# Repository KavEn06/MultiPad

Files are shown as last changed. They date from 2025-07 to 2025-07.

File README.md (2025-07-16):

# MultiPad


## Features
- Triple layer 3D printed case
- 128x32 OLED Display
- EC11 Rotary encoder for volume and scrolling through other shortcut layers 
- 6 keys
- Very cool swirly design – trust me, it looks awesome in person

## CAD Model
The CAD model is held together with 4 M3 screws and heatset inserts. It’s built in three layers: the bottom layer holds all the components, the middle layer keeps the switches in place, and the top layer is mainly there to look nice.

Case            |  Layers
:-------------------------:|:-------------------------:
 | 

The CAD model was made in OnShape. 

## PCB 
Here's the PCB! It utilizes a XIAO RP2040, which is connected to 6 switches, a 128x32 OLED display, and an EC11 rotary encoder. 

Schematic            |  PCB
:-------------------------:|:-------------------------:
 | 

Since I'm the goat, I got 0 errors after I did the DRC check. 😎

## BOM:
Here is a list of everything you would need to build the MultiPad

- 6x Cherry MX Switches
- 6x DSA Keycaps
- 4x M3x5x4 Heatset inserts
- 2X M3x12mm Bolts
- 1x 0.91" 128x32 OLED Display
- 1x EC11 Rotary Encoder
- 1x XIAO RP2040
- 1x Case (3 3D printed parts)

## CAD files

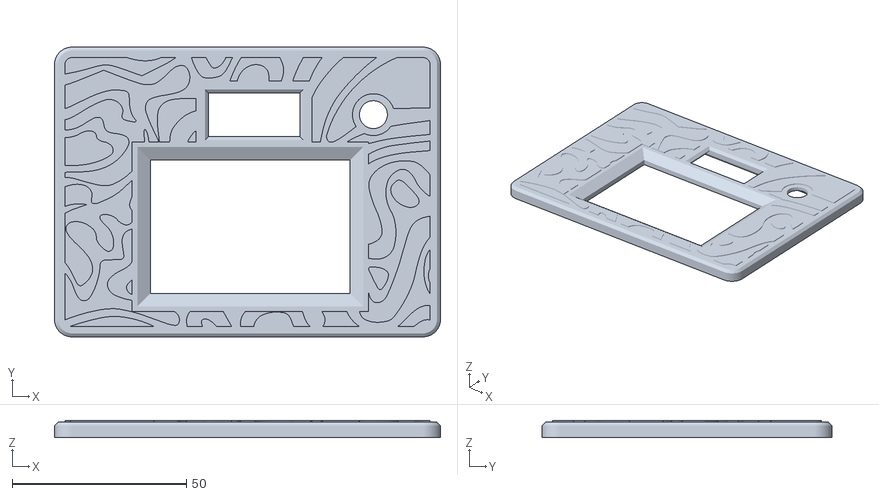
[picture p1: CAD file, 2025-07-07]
production/Top.stl
110.7 x 83.1 x 5.00

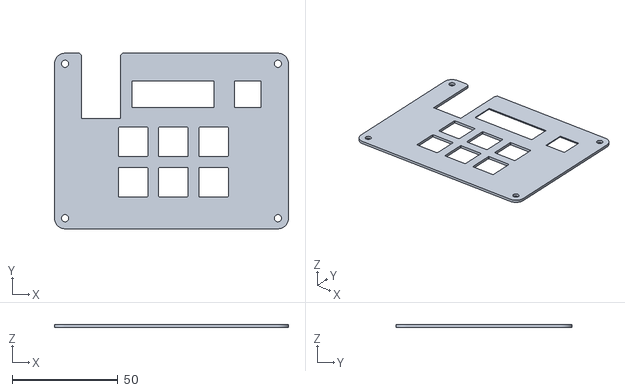
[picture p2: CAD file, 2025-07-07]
production/Middle.stl
110.8 x 83.1 x 1.40

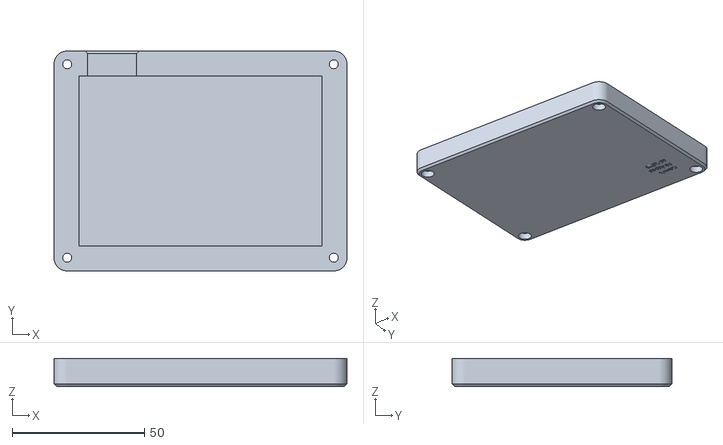
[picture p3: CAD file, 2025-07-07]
production/Bottom.stl
110.8 x 83.1 x 10.6

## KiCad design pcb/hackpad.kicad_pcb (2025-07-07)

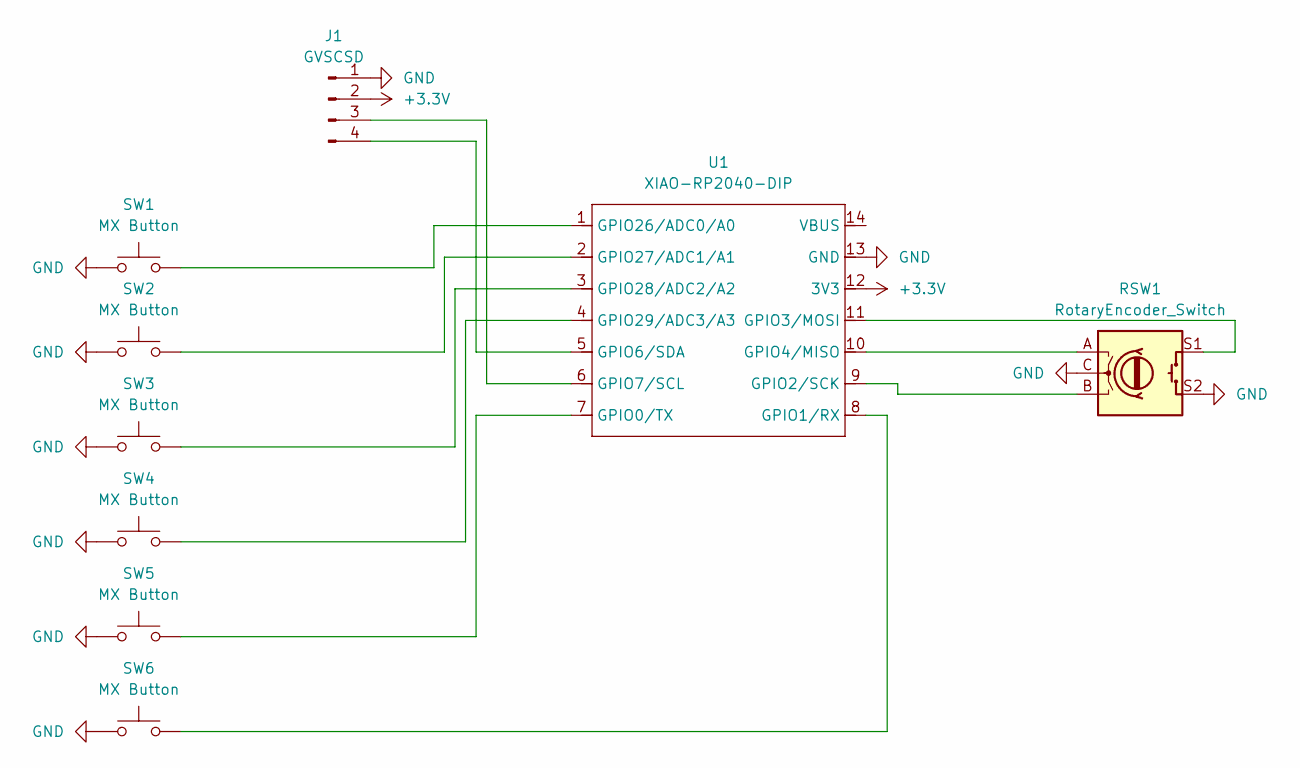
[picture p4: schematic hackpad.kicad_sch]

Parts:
J1: GVSCSD; SSD1306-0.91-OLED-4pin-128x32
RSW1: RotaryEncoder_Switch; RotaryEncoder_Alps_EC11E-Switch_Vertical_H20mm
SW1, SW2, SW3, SW4, SW5, SW6: MX Button; SW_Cherry_MX_1.00u_PCB
U1: XIAO-RP2040-DIP

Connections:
+3.3V: J1.2, U1.12 (3V3)
GND: J1.1, RSW1.C, RSW1.S2, SW1.1, SW2.1, SW3.1, SW4.1, SW5.1, SW6.1, U1.13 (GND)
unnamed: J1.3, U1.6 (GPIO7/SCL)
unnamed: J1.4, U1.5 (GPIO6/SDA)
unnamed: SW5.2, U1.7 (GPIO0/TX)
unnamed: SW6.2, U1.8 (GPIO1/RX)
unnamed: RSW1.B, U1.9 (GPIO2/SCK)
unnamed: RSW1.S1, U1.11 (GPIO3/MOSI)
unnamed: RSW1.A, U1.10 (GPIO4/MISO)
unnamed: SW1.2, U1.1 (GPIO26/ADC0/A0)
unnamed: SW2.2, U1.2 (GPIO27/ADC1/A1)
unnamed: SW3.2, U1.3 (GPIO28/ADC2/A2)
unnamed: SW4.2, U1.4 (GPIO29/ADC3/A3)

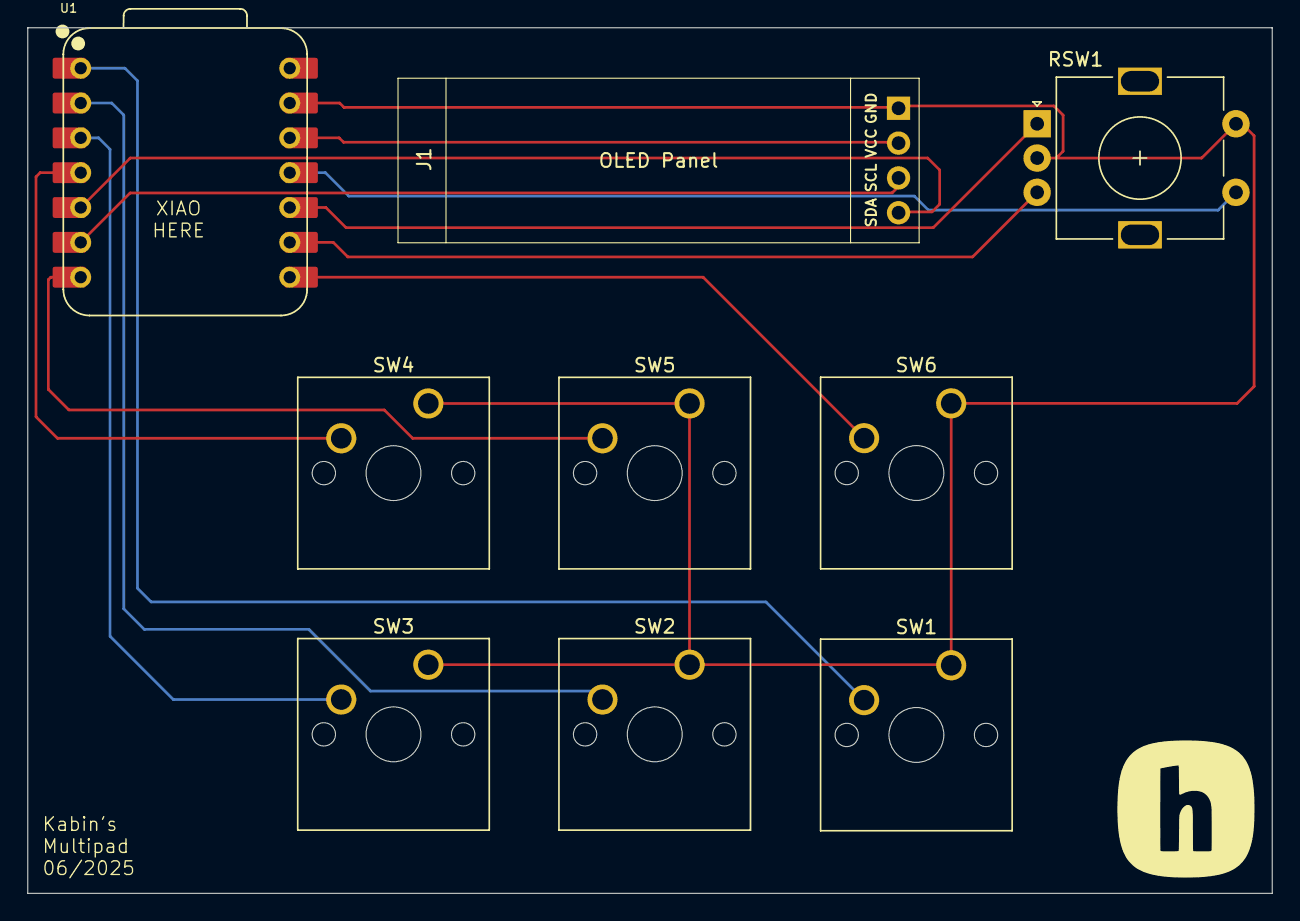
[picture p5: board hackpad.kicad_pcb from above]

Board: 2 copper layers, 90.8 x 63.1 mm, 10 parts (0 on the bottom side), 13 nets.

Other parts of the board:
G: LOGO

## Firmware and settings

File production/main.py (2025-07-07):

# You import all the IOs of your board
import board
import busio
import adafruit_ssd1306

# These are imports from the kmk library
from kmk.kmk_keyboard import KMKKeyboard
from kmk.scanners.keypad import KeysScanner
from kmk.keys import KC
from kmk.modules.layers import Layers
from kmk.modules.macros import Press, Release, Tap, Macros, Delay
from kmk.modules.encoder import EncoderHandler

# This is the main instance of your keyboard
keyboard = KMKKeyboard()
i2c = busio.I2C(board.SCL, board.SDA)

# global audio variable 
is_headphones = True 

# Add the macro extension
macros = Macros()
layers = Layers()
keyboard.modules.append(macros)
keyboard.modules.append(layers)
display = adafruit_ssd1306.SSD1306_I2C(128, 32, i2c)

# rotary encoder
class LayerScrollEncoder(EncoderHandler):
    def __init__(self):
        super().__init__()
        self.layer_scroll_mode = False
        self.selected_layer = 0
        self.max_layer = len(keyboard.keymap) - 1
        self.keymap_names = ["General", "VS Code", "OnShape", "Gaming"]
        
        display.fill(0)
        display.text(self.keymap_names[self.selected_layer], 0, 0, 1)
        display.show()

    def on_encoder_button(self, index, is_pressed):
        if is_pressed:
            self.layer_scroll_mode = True
            self.selected_layer = keyboard.active_layer
        else:
            self.layer_scroll_mode = False
            keyboard.active_layer = self.selected_layer

            display.fill(0)
            display.text(self.keymap_names[self.selected_layer], 0, 0, 1)
            display.show()

        return True  # Tell KMK we handled this


    def on_encoder_turn(self, encoder_index, clockwise):
        if self.layer_scroll_mode:
            # Scroll through layers while encoder button is held
            if clockwise:
                self.selected_layer = (self.selected_layer + 1) % (self.max_layer + 1)

                display.fill(0)
                display.text(self.keymap_names[self.selected_layer], 0, 0, 1)
                display.show()
            else:
                self.selected_layer = (self.selected_layer - 1) % (self.max_layer + 1)

                display.fill(0)
                display.text(self.keymap_names[self.selected_layer], 0, 0, 1)
                display.show()

            print(f"[Layer Scroll] Selected layer: {self.selected_layer}")
            return True  # Block default encoder behavior

        if keyboard.active_layer == 2:
            # CAD layer: Zoom in/out
            zoom_key = KC.LCTL(KC.EQL) if clockwise else KC.LCTL(KC.MINS)
            keyboard.tap_key(zoom_key)
            return True

        # Volume control
        volume_key = KC.VOLU if clockwise else KC.VOLD
        keyboard.tap_key(volume_key)
        return True

# output audio switcher 
def toggle_audio_output():
    global is_headphones
    
    sequence = [
        Tap(KC.LGUI(KC.B)),     Delay(150),  
        Tap(KC.RIGHT),          Delay(150),
        Tap(KC.ENTER),          Delay(250),
        Tap(KC.TAB),            Delay(150),
        Tap(KC.ENTER),          Delay(250),
    ]

    if is_headphones:
        sequence.append(Tap(KC.UP))   # Go to monitor
        is_headphones = False

    else:
        sequence.append(Tap(KC.DOWN)) # Go to headphones
        is_headphones = True

    sequence.append(Delay(200))
    sequence.append(Tap(KC.ENTER))  

    return KC.MACRO(*sequence)

#macros
open_gmail = KC.MACRO(
    Tap(KC.LCTL(KC.T)),
    Tap(KC.G), Tap(KC.M), Tap(KC.A), Tap(KC.I), Tap(KC.L),
    Tap(KC.DOT),
    Tap(KC.C), Tap(KC.O), Tap(KC.M),
    Tap(KC.ENTER)
)

git_clone = KC.MACRO(
    Tap(KC.LCTL(KC.LSFT(KC.P))),  

    Tap(KC.G), Tap(KC.I), Tap(KC.T), Tap(KC.COLON), Tap(KC.SPACE),
    Tap(KC.C), Tap(KC.L), Tap(KC.O), Tap(KC.N), Tap(KC.E),

    Tap(KC.ENTER),               
    Tap(KC.LCTL(KC.V)),           
    Tap(KC.ENTER)               
)

discord_mute = KC.MACRO(
    Tap(KC.LGUI(KC._1)),           
    Tap(KC.LCTL(KC.LSFT(KC.M))),
    Tap(KC.LALT(KC.TAB))            
)

discord_deafen = KC.MACRO(
    Tap(KC.LGUI(KC._1)),        
    Tap(KC.LCTL(KC.LSFT(KC.D))),  
    Tap(KC.LALT(KC.TAB))        
)

toggle_output = toggle_audio_output

# Define your pins here!
PINS = [
    board.GP29, board.GP0, board.GP1,
    board.GP28, board.GP27, board.GP26,
]

# Tell kmk we are not using a key matrix
keyboard.matrix = KeysScanner(
    pins=PINS,
    value_when_pressed=False,
)

# Here you define the buttons corresponding to the pins
# Look here for keycodes: https://github.com/KMKfw/kmk_firmware/blob/main/docs/en/keycodes.md
# And here for macros: https://github.com/KMKfw/kmk_firmware/blob/main/docs/en/macros.md
keyboard.keymap = [
    [
        toggle_output,          discord_mute,               KC.LGUI(KC.LSFT(KC.S)),
        KC.MEDIA_PREV_TRACK,    KC.MEDIA_NEXT_TRACK,        KC.MEDIA_PLAY_PAUSE,
    ],

    [
        KC.LCTL(KC.F5),         git_clone,                  KC.LSFT(KC.LALT(KC.DOWN)),
        KC.LCTL(KC.Z),          KC.LCTL(KC.SLSH),           KC.MEDIA_PLAY_PAUSE,
    ], 

    [
        KC.LSFT(KC._7),         KC.LSFT(KC.S),              KC.LSFT(KC.E),
        KC.LSFT(KC.X),          KC.LBRC,                    KC.MEDIA_PLAY_PAUSE,
    ],
    
    [
        toggle_output,          discord_mute,               discord_deafen,
        KC.NO,                  KC.NO,                      KC.NO,
    ]
]

encoder_handler = LayerScrollEncoder()
keyboard.modules.append(encoder_handler)
encoder_handler.pins = ((board.GP4, board.GP2, board.GP3, False),)

# Start kmk!
if __name__ == '__main__':
    keyboard.go()

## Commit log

2025-07-07 added stl files
    [Bottom (1).stl, Middle.stl, Top (5).stl]
2025-07-07 pcb files
    [hackpad.kicad_pcb, hackpad.kicad_sch]
2025-07-07 added gerber
